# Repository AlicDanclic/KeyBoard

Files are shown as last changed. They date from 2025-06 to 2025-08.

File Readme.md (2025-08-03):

<center><h1>客制化键盘 -- 主键盘部分</h1></center>

<hr style="border: none; height: 2px; background: linear-gradient(to right, #ff0000, #ff7f00, #ffff00, #00ff00, #0000ff, #4b0082, #8f00ff); width: 100%; margin: 0 auto;">
<div style="text-align: center; font-family: 'Times New Roman', serif; margin: 20px auto; max-width: 800px;">
    <div style="margin: 20px 0;">
    	User
    </div>
    <div style="font-weight: bold; font-size: 18px; color: #333; margin: 10px 0;">
    	Copyright Statement
    </div>
    <div style="font-size: 14px; color: #666; margin: 5px 0; font-family: 'SimSun', 'Times New Roman', serif;">
    	本文档/代码/作品受版权保护，版权所有@EternoPax。保留所有权利。
    </div>
    <div style="font-size: 14px; color: #666; margin: 5px 0; font-family: 'SimSun', 'Times New Roman', serif;">
        未经允许请勿转载<br>
        Do not reproduce without permission
    </div>
    <div style="font-size: 14px; color: #666; margin: 5px 0; font-family: 'SimSun', 'Times New Roman', serif;">
        联系我👉EternoPax@outlook.con
    </div>
    <div style="display: flex; align-items: center; justify-content: center; margin: 5px 0;">
        <span style="font-size: 14px; color: #666; font-family: 'SimSun', 'Times New Roman', serif; margin-right: 10px;">
            @Copyright EternoPax
        </span>
        Copyright
    </div>
</div>
<hr style="border: none; height: 2px; background: linear-gradient(to right, #ff0000, #ff7f00, #ffff00, #00ff00, #0000ff, #4b0082, #8f00ff); width: 100%; margin: 0 auto;">

> 作为一个客制化键盘的主键盘,在这里我将介绍我的学习过程,希望一起学习

### 基础介绍

作为一个客制化键盘来说,最基础的部分有外壳,PCB,定位板,键轴和键帽,而其他多大都是辅助使用,有了这些东西就基本可以做出来一个客制化键盘了。

### 键盘布局

> [Keyboard Layout Editor](https://www.keyboard-layout-editor.com/?ref=producthunt#/)

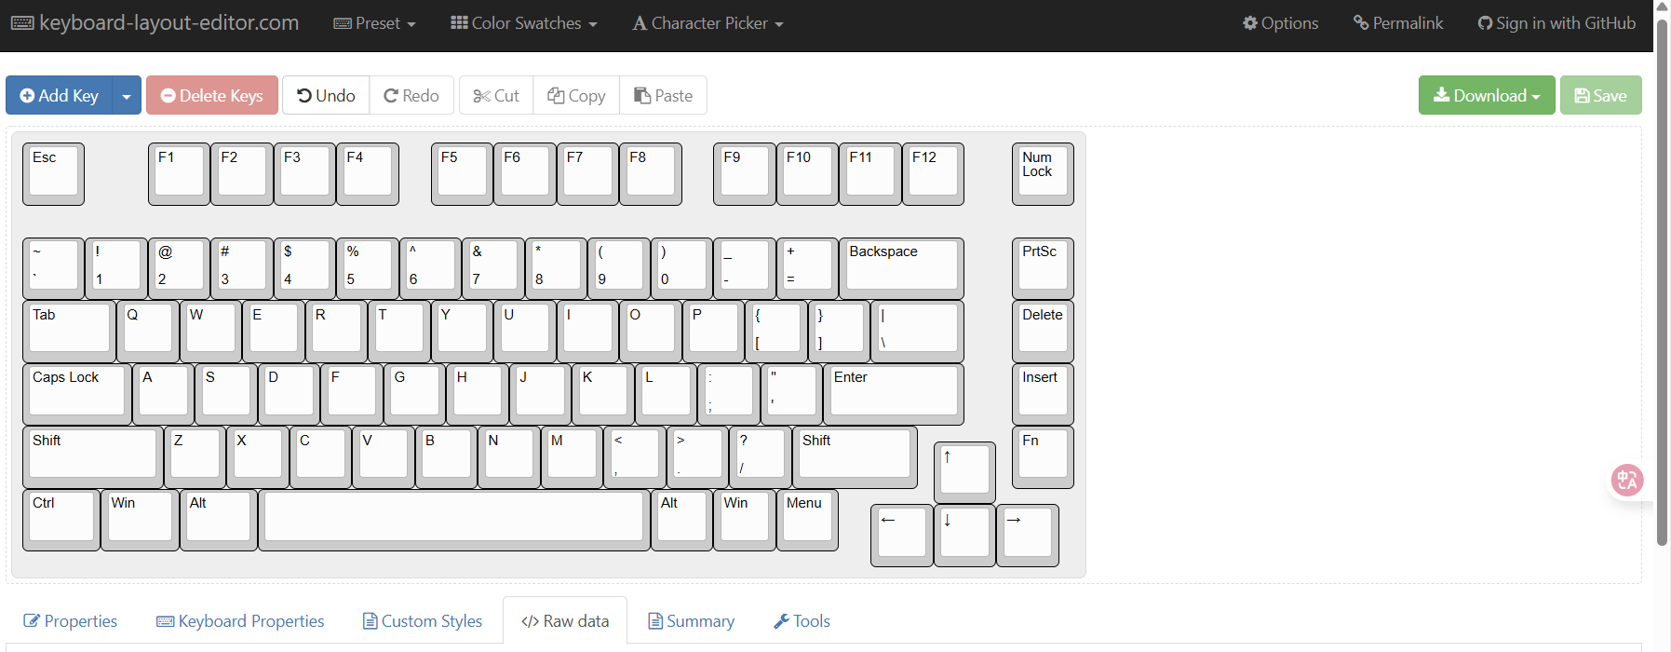
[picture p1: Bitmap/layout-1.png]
layout-1


这是通过网站设计的键盘布局,虽然这个网站的功能很多,当实际上用不到,笔者就简单介绍一下个人常用的几个功能.

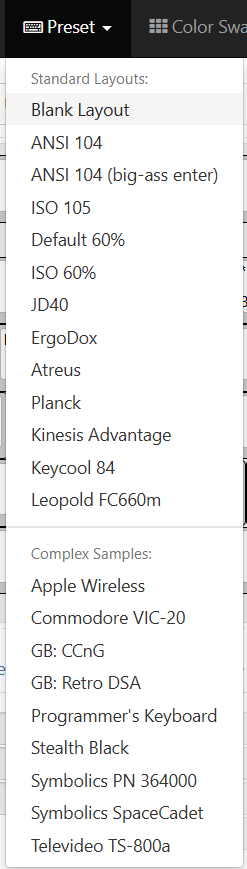
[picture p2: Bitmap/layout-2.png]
layout-2


在PreSet里面是我们常见的键盘布局,个人比较喜欢在ANSI104全键盘的基础上进行删减.

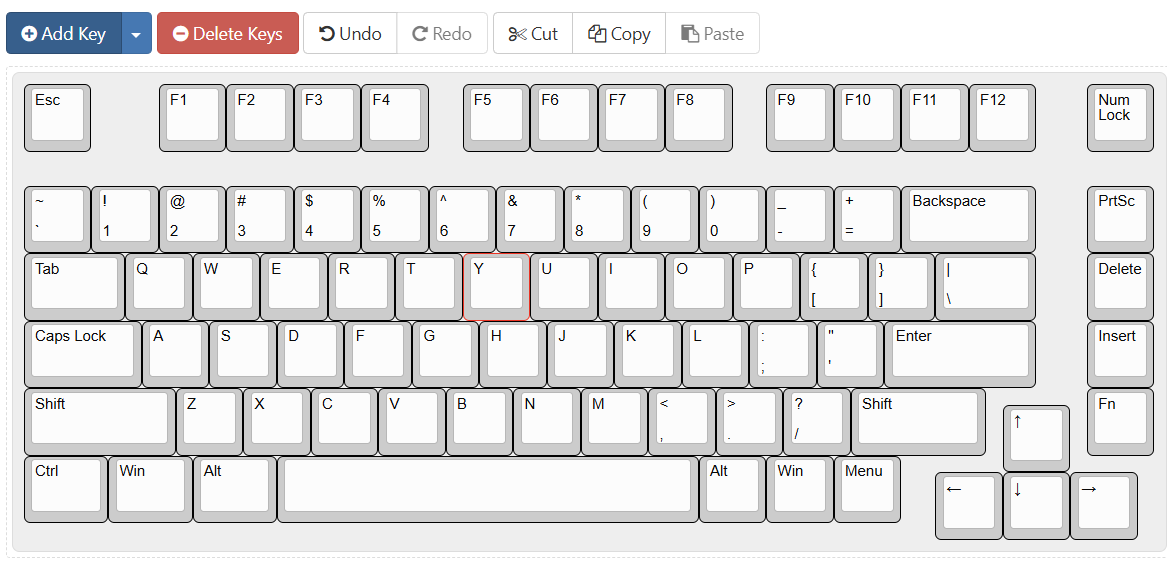
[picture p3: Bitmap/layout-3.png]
layout-3


在当你选中其中的一个按键,上边的DeleteKeys会亮起,你可以直接使用Delete进行删除,也可以左键选中按下Delete一起删除(注意:选中会出现一个框,只有完全在框里的按键会被选中)

选中按键后可以按下方向键来调整位置

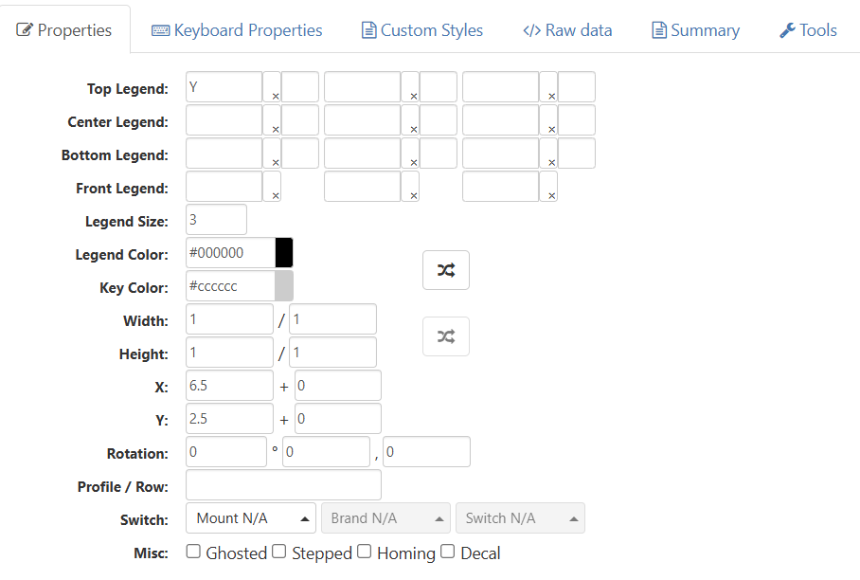
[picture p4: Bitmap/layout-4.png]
layout-4


在

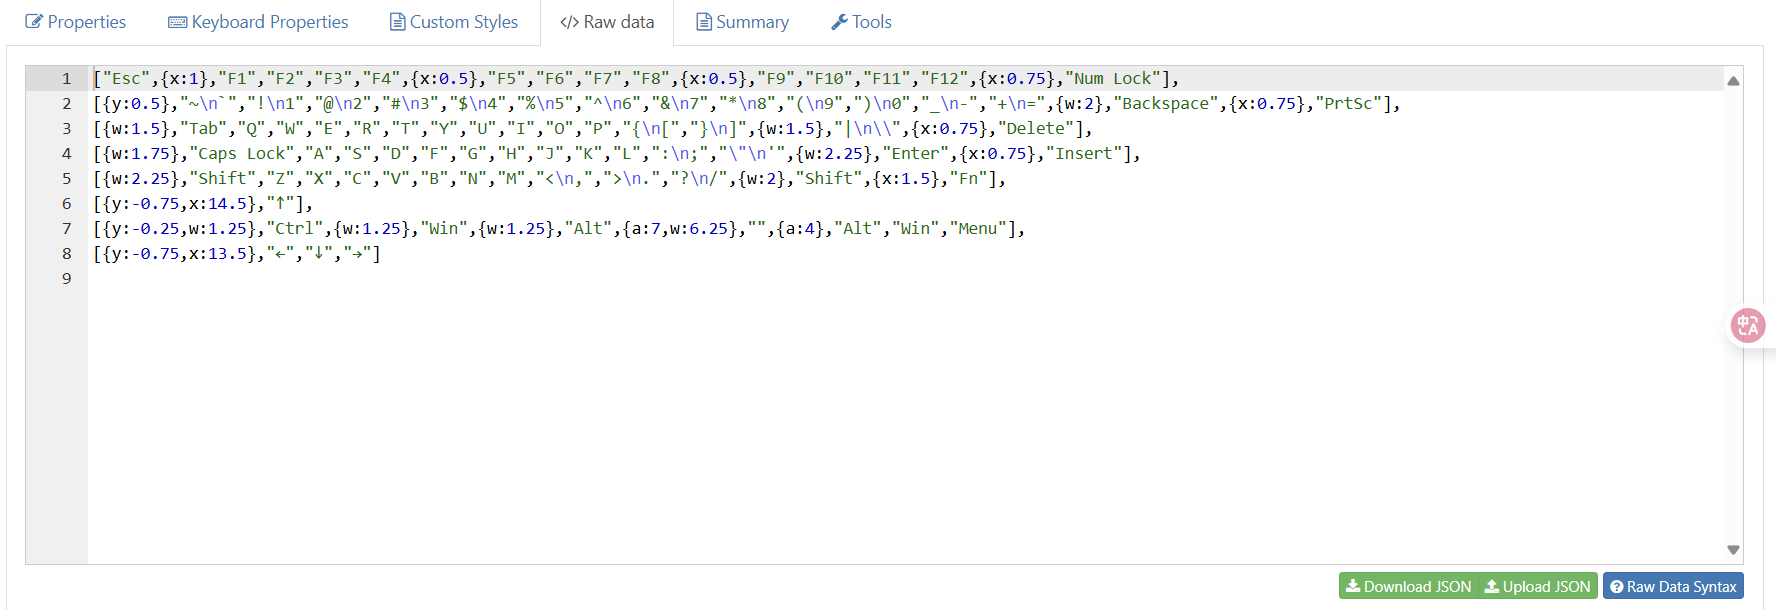
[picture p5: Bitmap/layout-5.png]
layout-5


在Raw data里面是我们键盘的布局格式,这个是我们以后用来绘制CAD的数据

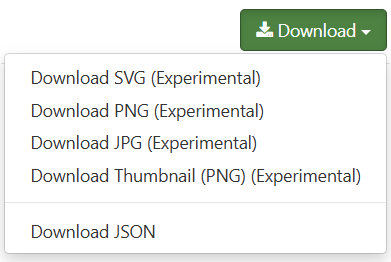
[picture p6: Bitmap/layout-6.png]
layout-6


在右上角可以看到Download,请你再绘制好之后务必下载JSON和SVG,其中JSON是为了方便以后再进行layout的修改,而SVG是为了之后的键帽设计做准备.

### 原理图绘制

### PCB绘制

### 键帽设计

### 3D外壳

### 固件编写

### 最终成果

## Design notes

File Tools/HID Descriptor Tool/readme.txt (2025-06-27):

Descriptor Tool, Version 2.4

The major changes to 2.4 are:

1) Fixed monitor enumerated values. Needed to have usage 1 display "Enum 0".
   Added REPEATING0 option to .UPG files to fix this.

2) Added a title bar to the Usage Page Dialog box.

3) Fixed incorrect Extended Usages during inital insertion.

4) Added concatonation of Ordinal Instance value to Usages in collection
   immediately following Ordinal declaration.

5) Fixed display of Extended Usages when No Data option is selected.

6) Added support for Vendor Defined Usage Tables.

The major changes to Version 2.3 are:

1) added sizable window

The major changes to 2.0 are:

1) Incorporated the HID syntax checker from HIDview.

2) The Usage Pages are all ASCII files that can be modified by the user.

3) Extended Usages are supported.

4) Added cut and paste.

5) Report Descriptors files can be saved as .HID, .TXT, .INC, and .H. Only .HID can be read. 

6) Included examples from the HID spec. and the Usage Table document.

7) Fixed numerous bugs.

/************************************************************************
Instructions:

DT.INI must reside in the same directory as DT.EXE.

Usage pages can be added or modified. To add a Usage Page create a text
.UPG file as described below then add an Usage Page (UPn) entry to DT.INI.

NOTE: When saving a file in a format other than .HID be sure to
change the extension otherwise the .HID file will be overwritten.

****************************     WARNING      ***************************
The usages pages (.UPG files) from the 9.0 Release Candidate USB HID Usage
Tables document are included here. These pages are included for convienence
and may change in the final release of the document.
****************************     WARNING      ***************************

/************************************************************************
HID Spec issues:

1) Vendor defined Collection IDs are not supported by DT.

2) Extended Usages are 32-bit usages where the high order 16-bits are the
Usage Page ID and the low order 16-bits are the Usage ID. These are useful
when usages from different Usage Pages are required for the same Main Item.
Memphis supports extended usages. Extended Usages are not defined in the
HID 1.0 Specification.

3) Extended usage values for Usage Minimum and Maximum (32 bit parameters)
are also supported by DT. Memphis supports this too.

4) Memphis has the following restrictions on delimiters:
 - Do not use delimiters for usages associated with top level (application)
       collections.
 - Only Usages are supported in delimiters. Usage Min, Usage Max, Designators
       and Strings are NOT allowed in a delimited set.
 - Delimiters are not allowed when defining usages associated with an Array.

5) The checker (Parse Descriptor) does not support:
 -- Push and Pop - False errors will be reported due to state variables that
are not saved and restored.

 -- Extended Usages - The checker will report extended usages as "undefined"
because it does not break the 32-bit value into Usage and Usage Page.

Report problems to: steve_mcgowan@ccm.jf.intel.com

/************************************************************************
File format definitions:

/************************************************************************
.INI format

[UsagePages]
Count=<total number of usage pages declared>
UP0=<Usage Page ID>,<Usage Page Name>,<.UPG File Name>
UP1=...
...
UP<Count - 1>=...

  UPn, where n increments from 0 to the number of pages declared - 1

Notes:
  The .INI file must be in the same directory as DT.EXE.

  The Usage Page ID is in decimal.

  The Usage Page Name must be identical to that found in the .UPG file.

  The .UPG File Name can include a path.

*************************************************************************
.UPG format

There are 2 types of .UPG files: NORMAL and REPEATING.

NORMAL .UPG files

<Usage Page Name>
<.UPG File Type Flag: NORMAL>
<Usage ID><tab ('\t')><Usage Name> or
; Comment if ';' is first character of a line (ignored) or
<Usage ID-Usage ID><tab><Reserved of reserved> (ignored)

	Notes:
	The Usage Page Name must be identical to the Usage Page Name referred
	to in the .INI file to be recognized as a .UPG file.

	No blank lines can be in the file.

    The Usage ID is in hexidecimal with NO "0x" notation preceeding it
	or "h" following it.

	There are three forms that can follow the File Type Flag:
		1) The Usage ID, followed by a tab character, followed by the
		Usage Name Spaces are allowed in Usage names.
		2) Any line with a semi-colon as the first character is
		considered a comment and ignored.
		3) Any line that has  "Reserved" of "reserved" as the
		Usage Name will be considered a comment and ignored.
		4) Comments are only allowed after the UPG File Type Flag.

  Example:

Generic Desktop
NORMAL
00	Undefined
01	Pointer
02	Mouse
03	Reserved
04	Joystick
05	Game Pad
06	Keyboard
07	Keypad
08-2F	Reserved
30	X
...
81	System Power
82	System Sleep
83-FFFF	Reserved

REPEATING .UPG files

<Usage Page Name>
<.UPG File Type Flag: REPEATING>
00<tab ('\t')><first Usage Name>
01<tab ('\t')><repeated Usage Name>
; Comment if ';' is first character of a line (ignored)

	Notes:
	The Usage Page Name must be identical to the Usage Page Name referred
	to in the .INI file to be recognized as a .UPG file.

	No blank lines can be in the file.

	Only 2 usages are declared. The Usage Name of the first entry (00)
	will be used for the first usage and the Usage Name of the second
	entry will be repeated followed by <space><Usage ID>.

	There are three forms that can follow the File Type Flag:
		1) The Usage ID, followed by a tab character, followed by the
		Usage Name Spaces are allowed in Usage names.
		2) Any line with a semi-colon as the first character is
		considered a comment and ignored.
		3) Any line that has  "Reserved" of "reserved" as the
		Usage Name will be considered a comment and ignored.
		4) Comments are only allowed after the UPG File Type Flag.

  Example:

Button
REPEATING
00	Unused
01	Button

  Results in the usages:

Unused
Button 1
Button 2
Button 3
...

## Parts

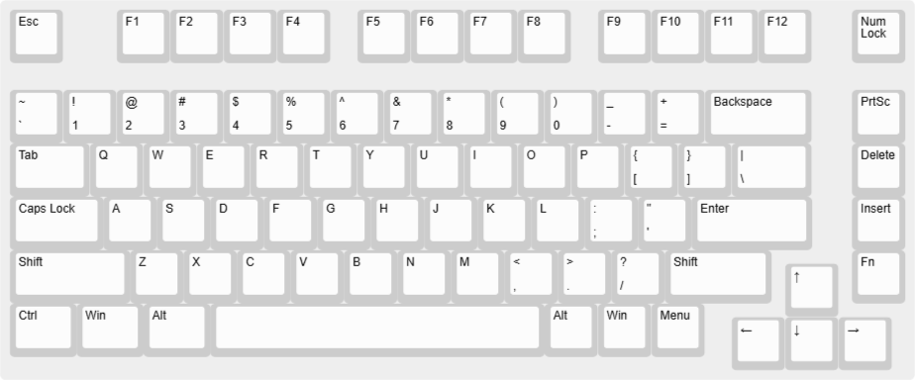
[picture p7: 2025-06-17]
Bitmap/keyboard-order.png

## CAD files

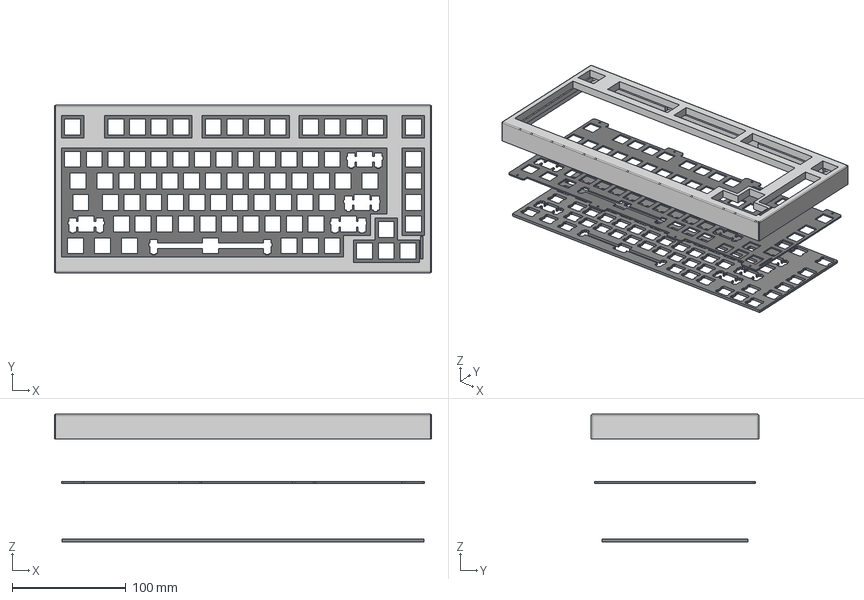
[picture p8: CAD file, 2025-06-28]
Hardware/3D/键盘.step
332.0 x 147.5 x 112.5 mm
零部件1
零部件2

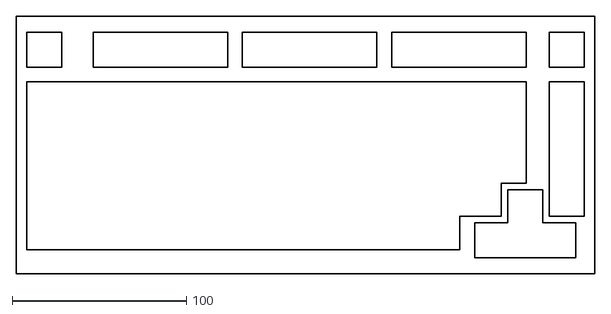
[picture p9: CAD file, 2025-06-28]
Hardware/CAD/Enclosure.dxf
332.0 x 147.5

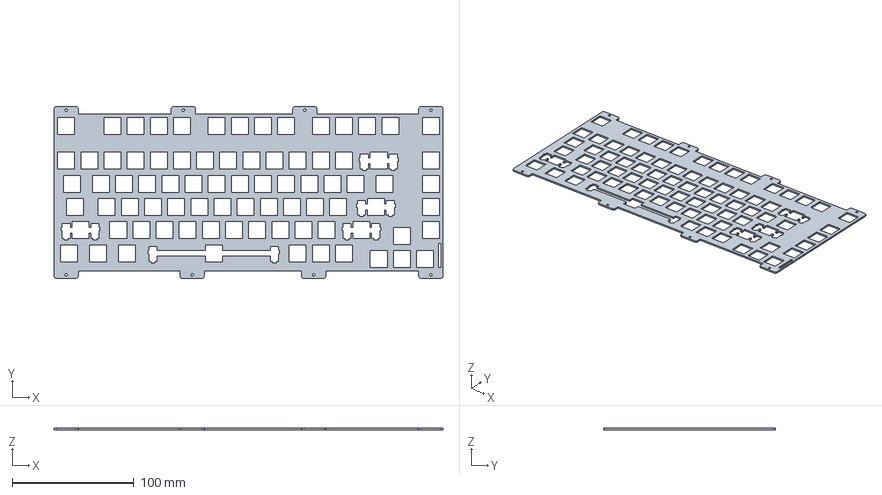
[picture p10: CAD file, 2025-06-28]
Hardware/3D/定位板.step
320.0 x 141.5 x 1.50 mm

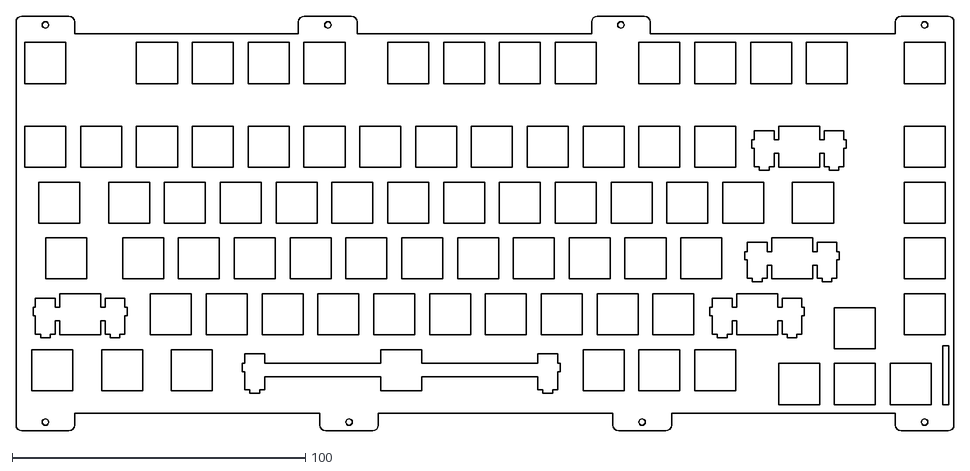
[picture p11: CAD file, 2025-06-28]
Hardware/CAD/Locating plates.dxf
320.0 x 141.5

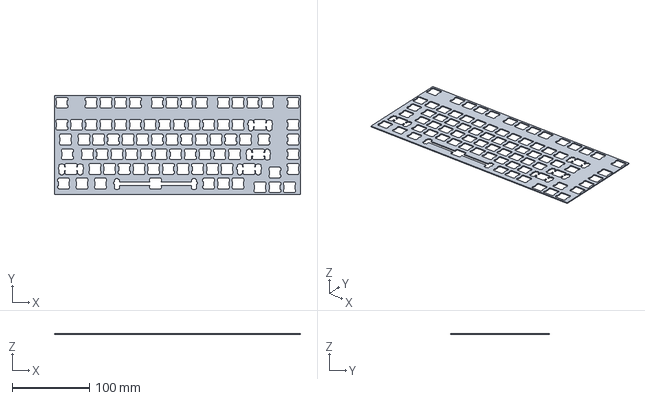
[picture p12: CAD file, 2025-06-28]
Hardware/3D/PCB模拟.step
319.1 x 128.6 x 1.20 mm

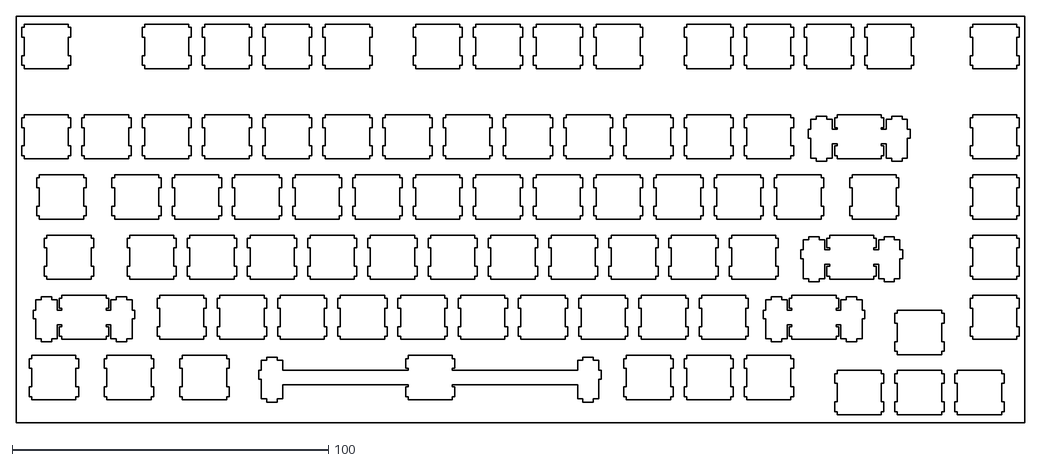
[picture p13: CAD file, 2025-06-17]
Hardware/CAD/PCB_Layout.dxf
319.1 x 128.6

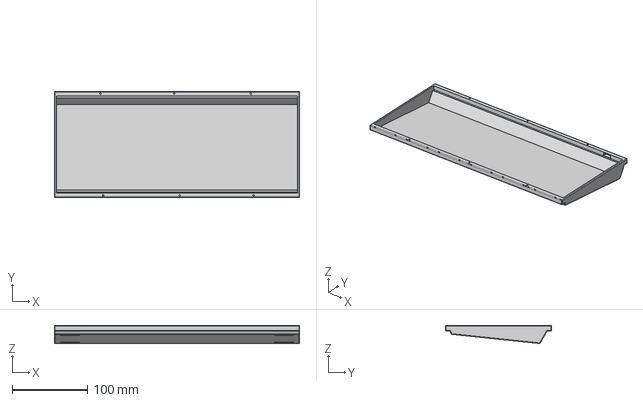
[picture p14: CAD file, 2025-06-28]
Hardware/3D/下壳.step
325.9 x 141.4 x 24.0 mm

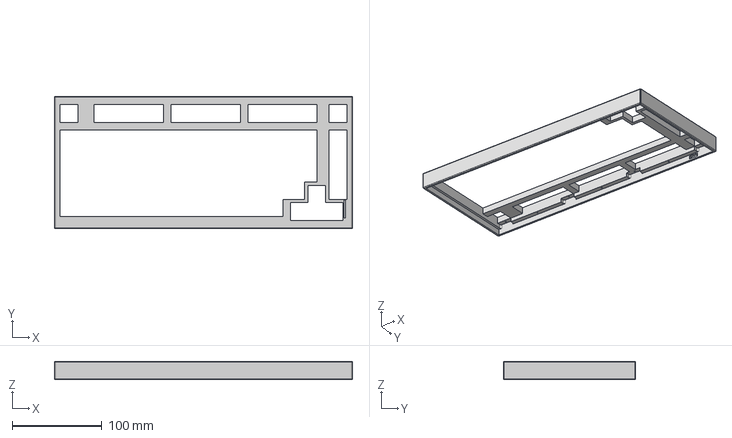
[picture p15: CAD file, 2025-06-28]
Hardware/3D/顶壳.step
332.0 x 147.5 x 20.5 mm

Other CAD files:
Hardware/3D/键盘.f3d

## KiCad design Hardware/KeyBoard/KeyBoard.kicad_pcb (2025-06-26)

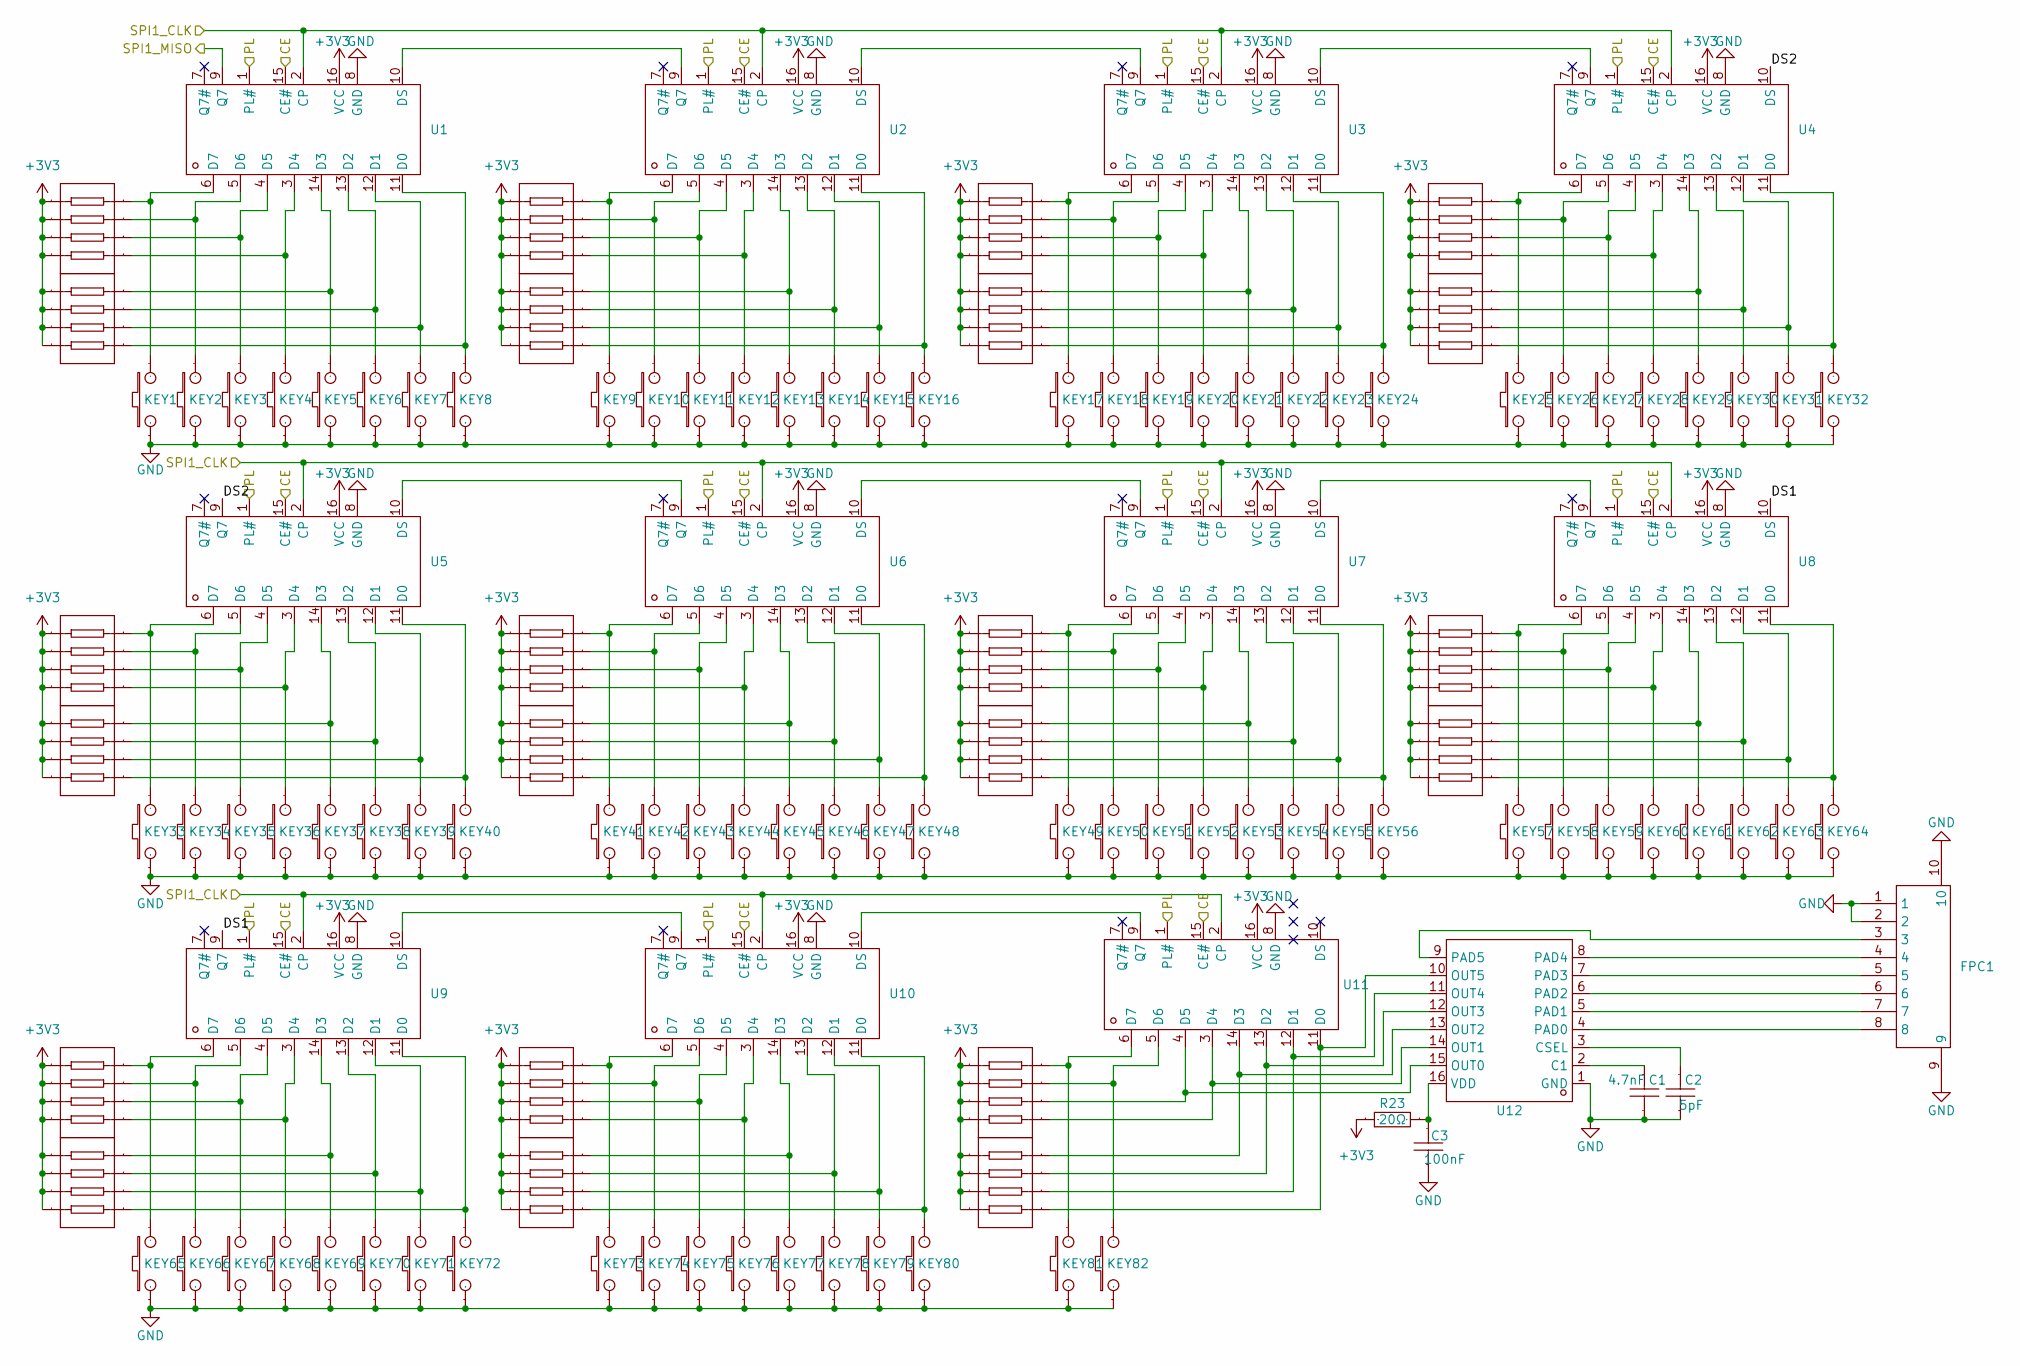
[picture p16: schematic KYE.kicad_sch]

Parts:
C1: 4.7nF; C0402; Manufacturer Part 0402B472K500NT; LCSC Part Name 4.7nF ±10% 50V
C2: 5pF; C0402; Manufacturer Part 0402B472K500NT; LCSC Part Name 4.7nF ±10% 50V
C3: 100nF; C0402; Manufacturer Part 0402B472K500NT; LCSC Part Name 4.7nF ±10% 50V
FPC1: FPC-SMD_P0.50-8P_FGS-XJ-H2.0; Manufacturer Part AFC01-S08FCA-00; LCSC Part Name 0.5mm P数:8 翻盖式 下接
KEY1, KEY2, KEY3, KEY4, KEY5, KEY6, KEY7, KEY8, KEY9, KEY10, KEY11, KEY12, KEY13, KEY14, KEY15, KEY16, KEY17, KEY18, KEY19, KEY20, KEY21, KEY22, KEY23, KEY24, KEY25, KEY26, KEY27, KEY28, KEY29, KEY30, KEY31, KEY32, KEY33, KEY34, KEY35, KEY36, KEY37, KEY38, KEY39, KEY40, KEY41, KEY42, KEY43, KEY44, KEY45, KEY46, KEY47, KEY48, KEY49, KEY50, KEY51, KEY52, KEY53, KEY54, KEY55, KEY56, KEY57, KEY58, KEY59, KEY60, KEY61, KEY62, KEY63, KEY64, KEY65, KEY66, KEY67, KEY68, KEY69, KEY70, KEY71, KEY72, KEY73, KEY74, KEY75, KEY76, KEY77, KEY78, KEY79, KEY80, KEY81, KEY82: MX-KEY-INSTALLED
R1, R2, R3, R4, R5, R6, R7, R8, R9, R10, R11, R12, R13, R14, R15, R16, R17, R18, R19, R20, R21, R22: 10kΩ; RES-ARRAY-SMD_0603-8P-L3.2-W1.6-BL; Manufacturer Part 4D03WGJ0103T5E; LCSC Part Name 10kΩ ±5%
R23: 20Ω; R0402; Manufacturer Part 0402WGF220JTCE; LCSC Part Name 22Ω ±1% 62.5mW
U1, U2, U3, U4, U5, U6, U7, U8, U9, U10, U11: SOIC-16_L9.9-W3.9-P1.27-LS6.0-BL; Manufacturer Part 74HC165D,653; LCSC Part Name 74HC165D,653
U12: SOP-16_L10.0-W3.9-P1.27-LS6.0-BL; Manufacturer Part XW06A; LCSC Part Name XW06A

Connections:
+3V3: R1.5, R1.6, R1.7, R1.8, R2.5, R2.6, R2.7, R2.8, R3.5, R3.6, R3.7, R3.8, R4.5, R4.6, R4.7, R4.8, R5.5, R5.6, R5.7, R5.8, R6.5, R6.6, R6.7, R6.8, R7.5, R7.6, R7.7, R7.8, R8.5, R8.6, R8.7, R8.8, R9.5, R9.6, R9.7, R9.8, R10.5, R10.6, R10.7, R10.8, R11.5, R11.6, R11.7, R11.8, R12.5, R12.6, R12.7, R12.8, R13.5, R13.6, R13.7, R13.8, R14.5, R14.6, R14.7, R14.8, R15.5, R15.6, R15.7, R15.8, R16.5, R16.6, R16.7, R16.8, R17.5, R17.6, R17.7, R17.8, R18.5, R18.6, R18.7, R18.8, R19.5, R19.6, R19.7, R19.8, R20.5, R20.6, R20.7, R20.8, R21.5, R21.6, R21.7, R21.8, R22.5, R22.6, R22.7, R22.8, R23.1, U1.16 (VCC), U2.16 (VCC), U3.16 (VCC), U4.16 (VCC), U5.16 (VCC), U6.16 (VCC), U7.16 (VCC), U8.16 (VCC), U9.16 (VCC), U10.16 (VCC), U11.16 (VCC); also elsewhere on the board
/KEY/CE: U1.15 (CE#), U2.15 (CE#), U3.15 (CE#), U4.15 (CE#), U5.15 (CE#), U6.15 (CE#), U7.15 (CE#), U8.15 (CE#), U9.15 (CE#), U10.15 (CE#), U11.15 (CE#); also elsewhere on the board
/KEY/DS1: U8.10 (DS), U9.9 (Q7)
/KEY/DS2: U4.10 (DS), U5.9 (Q7)
/KEY/PL: U1.1 (PL#), U2.1 (PL#), U3.1 (PL#), U4.1 (PL#), U5.1 (PL#), U6.1 (PL#), U7.1 (PL#), U8.1 (PL#), U9.1 (PL#), U10.1 (PL#), U11.1 (PL#); also elsewhere on the board
/KEY/SPI1_CLK: U1.2 (CP), U2.2 (CP), U3.2 (CP), U4.2 (CP), U5.2 (CP), U6.2 (CP), U7.2 (CP), U8.2 (CP), U9.2 (CP), U10.2 (CP), U11.2 (CP); also elsewhere on the board
/KEY/SPI1_MISO: U1.9 (Q7); also elsewhere on the board
GND: C1.2, C2.1, C3.1, FPC1.1, FPC1.2, FPC1.9, FPC1.10, KEY1.1, KEY2.1, KEY3.1, KEY4.1, KEY5.1, KEY6.1, KEY7.1, KEY8.1, KEY9.1, KEY10.1, KEY11.1, KEY12.1, KEY13.1, KEY14.1, KEY15.1, KEY16.1, KEY17.1, KEY18.1, KEY19.1, KEY20.1, KEY21.1, KEY22.1, KEY23.1, KEY24.1, KEY25.1, KEY26.1, KEY27.1, KEY28.1, KEY29.1, KEY30.1, KEY31.1, KEY32.1, KEY33.1, KEY34.1, KEY35.1, KEY36.1, KEY37.1, KEY38.1, KEY39.1, KEY40.1, KEY41.1, KEY42.1, KEY43.1, KEY44.1, KEY45.1, KEY46.1, KEY47.1, KEY48.1, KEY49.1, KEY50.1, KEY51.1, KEY52.1, KEY53.1, KEY54.1, KEY55.1, KEY56.1, KEY57.1, KEY58.1, KEY59.1, KEY60.1, KEY61.1, KEY62.1, KEY63.1, KEY64.1, KEY65.1, KEY66.1, KEY67.1, KEY68.1, KEY69.1, KEY70.1, KEY71.1, KEY72.1, KEY73.1, KEY74.1, KEY75.1, KEY76.1, KEY77.1, KEY78.1, KEY79.1, KEY80.1, KEY81.1, KEY82.1, U1.8 (GND), U2.8 (GND), U3.8 (GND), U4.8 (GND), U5.8 (GND), U6.8 (GND), U7.8 (GND), U8.8 (GND), U9.8 (GND), U10.8 (GND), U11.8 (GND), U12.1 (GND); also elsewhere on the board
unnamed: KEY8.2, R2.4, U1.11 (D0)
unnamed: KEY7.2, R2.3, U1.12 (D1)
unnamed: KEY6.2, R2.2, U1.13 (D2)
unnamed: KEY5.2, R2.1, U1.14 (D3)
unnamed: KEY4.2, R1.4, U1.3 (D4)
unnamed: KEY3.2, R1.3, U1.4 (D5)
unnamed: KEY2.2, R1.2, U1.5 (D6)
unnamed: KEY1.2, R1.1, U1.6 (D7)
unnamed: U1.10 (DS), U2.9 (Q7)
unnamed: KEY16.2, R4.4, U2.11 (D0)
unnamed: KEY15.2, R4.3, U2.12 (D1)
unnamed: KEY14.2, R4.2, U2.13 (D2)
unnamed: KEY13.2, R4.1, U2.14 (D3)
unnamed: KEY12.2, R3.4, U2.3 (D4)
unnamed: KEY11.2, R3.3, U2.4 (D5)
unnamed: KEY10.2, R3.2, U2.5 (D6)
unnamed: KEY9.2, R3.1, U2.6 (D7)
unnamed: U2.10 (DS), U3.9 (Q7)
unnamed: KEY24.2, R6.4, U3.11 (D0)
unnamed: KEY23.2, R6.3, U3.12 (D1)
unnamed: KEY22.2, R6.2, U3.13 (D2)
unnamed: KEY21.2, R6.1, U3.14 (D3)
unnamed: KEY20.2, R5.4, U3.3 (D4)
unnamed: KEY19.2, R5.3, U3.4 (D5)
unnamed: KEY18.2, R5.2, U3.5 (D6)
unnamed: KEY17.2, R5.1, U3.6 (D7)
unnamed: U3.10 (DS), U4.9 (Q7)
unnamed: KEY32.2, R8.4, U4.11 (D0)
unnamed: KEY31.2, R8.3, U4.12 (D1)
unnamed: KEY30.2, R8.2, U4.13 (D2)
unnamed: KEY29.2, R8.1, U4.14 (D3)
unnamed: KEY28.2, R7.4, U4.3 (D4)
unnamed: KEY27.2, R7.3, U4.4 (D5)
unnamed: KEY26.2, R7.2, U4.5 (D6)
unnamed: KEY25.2, R7.1, U4.6 (D7)
unnamed: KEY40.2, R10.4, U5.11 (D0)
unnamed: KEY39.2, R10.3, U5.12 (D1)
unnamed: KEY38.2, R10.2, U5.13 (D2)
unnamed: KEY37.2, R10.1, U5.14 (D3)
unnamed: KEY36.2, R9.4, U5.3 (D4)
unnamed: KEY35.2, R9.3, U5.4 (D5)
unnamed: KEY34.2, R9.2, U5.5 (D6)
unnamed: KEY33.2, R9.1, U5.6 (D7)
unnamed: U5.10 (DS), U6.9 (Q7)
unnamed: KEY48.2, R12.4, U6.11 (D0)
unnamed: KEY47.2, R12.3, U6.12 (D1)
unnamed: KEY46.2, R12.2, U6.13 (D2)
unnamed: KEY45.2, R12.1, U6.14 (D3)
unnamed: KEY44.2, R11.4, U6.3 (D4)
unnamed: KEY43.2, R11.3, U6.4 (D5)
unnamed: KEY42.2, R11.2, U6.5 (D6)
unnamed: KEY41.2, R11.1, U6.6 (D7)
unnamed: U6.10 (DS), U7.9 (Q7)
unnamed: KEY56.2, R14.4, U7.11 (D0)
unnamed: KEY55.2, R14.3, U7.12 (D1)
unnamed: KEY54.2, R14.2, U7.13 (D2)
unnamed: KEY53.2, R14.1, U7.14 (D3)
unnamed: KEY52.2, R13.4, U7.3 (D4)
unnamed: KEY51.2, R13.3, U7.4 (D5)
unnamed: KEY50.2, R13.2, U7.5 (D6)
unnamed: KEY49.2, R13.1, U7.6 (D7)
unnamed: U7.10 (DS), U8.9 (Q7)
unnamed: KEY64.2, R16.4, U8.11 (D0)
unnamed: KEY63.2, R16.3, U8.12 (D1)
unnamed: KEY62.2, R16.2, U8.13 (D2)
unnamed: KEY61.2, R16.1, U8.14 (D3)
unnamed: KEY60.2, R15.4, U8.3 (D4)
unnamed: KEY59.2, R15.3, U8.4 (D5)
unnamed: KEY58.2, R15.2, U8.5 (D6)
unnamed: KEY57.2, R15.1, U8.6 (D7)
unnamed: KEY72.2, R18.4, U9.11 (D0)
unnamed: KEY71.2, R18.3, U9.12 (D1)
unnamed: KEY70.2, R18.2, U9.13 (D2)
unnamed: KEY69.2, R18.1, U9.14 (D3)
unnamed: KEY68.2, R17.4, U9.3 (D4)
unnamed: KEY67.2, R17.3, U9.4 (D5)
unnamed: KEY66.2, R17.2, U9.5 (D6)
unnamed: KEY65.2, R17.1, U9.6 (D7)
unnamed: KEY80.2, R20.4, U10.11 (D0)
unnamed: KEY79.2, R20.3, U10.12 (D1)
unnamed: KEY78.2, R20.2, U10.13 (D2)
unnamed: KEY77.2, R20.1, U10.14 (D3)
unnamed: KEY76.2, R19.4, U10.3 (D4)
unnamed: KEY75.2, R19.3, U10.4 (D5)
unnamed: KEY74.2, R19.2, U10.5 (D6)
unnamed: KEY73.2, R19.1, U10.6 (D7)
unnamed: U10.10 (DS), U11.9 (Q7)
unnamed: U9.10 (DS), U10.9 (Q7)
unnamed: R22.4, U11.11 (D0), U12.10 (OUT5)
unnamed: R22.3, U11.12 (D1), U12.11 (OUT4)
unnamed: R22.2, U11.13 (D2), U12.12 (OUT3)
unnamed: R22.1, U11.14 (D3), U12.13 (OUT2)
unnamed: R21.4, U11.3 (D4), U12.14 (OUT1)
unnamed: R21.3, U11.4 (D5), U12.15 (OUT0)
unnamed: KEY82.2, R21.2, U11.5 (D6)
unnamed: KEY81.2, R21.1, U11.6 (D7)
unnamed: C1.1, U12.2 (C1)
unnamed: C2.2, U12.3 (CSEL)
unnamed: FPC1.8, U12.4 (PAD0)
unnamed: FPC1.7, U12.5 (PAD1)
unnamed: FPC1.6, U12.6 (PAD2)
unnamed: FPC1.5, U12.7 (PAD3)
unnamed: FPC1.4, U12.8 (PAD4)
unnamed: FPC1.3, U12.9 (PAD5)
unnamed: C3.2, R23.2, U12.16 (VDD)

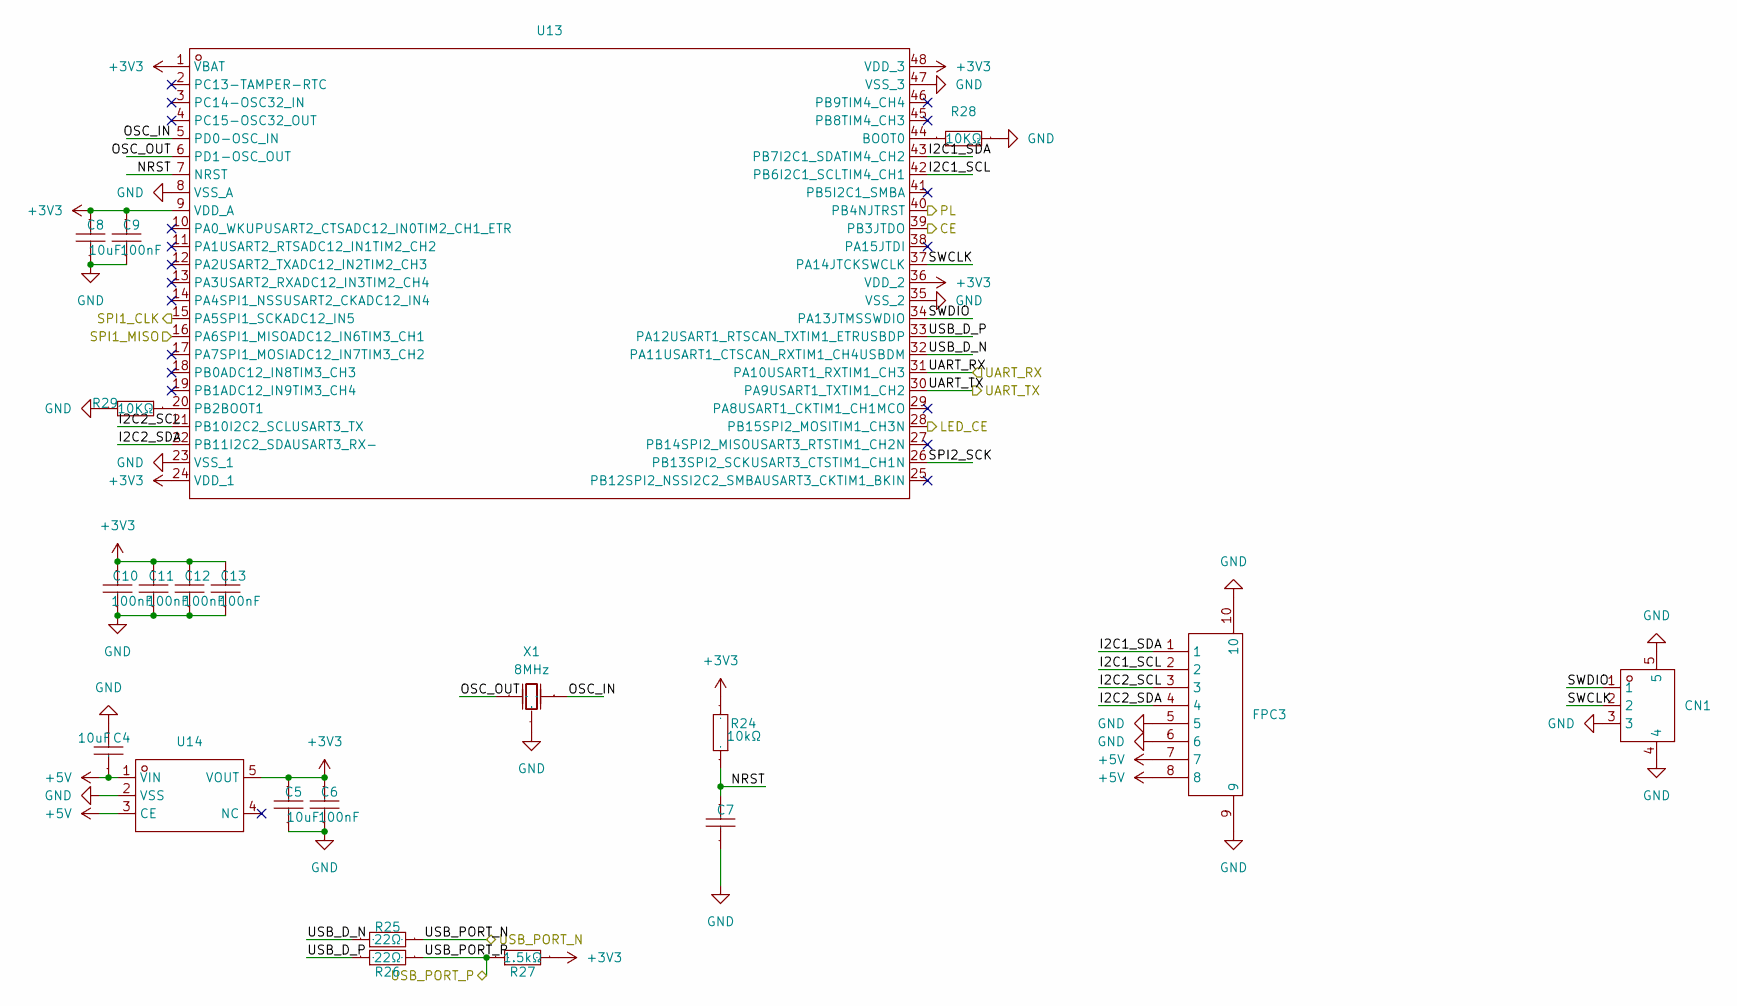
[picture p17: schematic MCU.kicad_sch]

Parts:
C4, C5, C8: 10uF; C0402; Manufacturer Part 0402B472K500NT; LCSC Part Name 4.7nF ±10% 50V
C6, C7, C9, C10, C11, C12, C13: 100nF; C0402; Manufacturer Part 0402B472K500NT; LCSC Part Name 4.7nF ±10% 50V
CN1: CONN-TH_3P-P1.25_GH1.25; Manufacturer Part WAFER-GH1.25-3PWB; LCSC Part Name 1x3P 间距:1.25mm 卧贴 系列:GH
FPC3: FPC-SMD_P0.50-8P_FGS-XJ-H2.0; Manufacturer Part AFC01-S08FCA-00; LCSC Part Name 0.5mm P数:8 翻盖式 下接
R24: 10kΩ; R0402; Manufacturer Part 0402WGF220JTCE; LCSC Part Name 22Ω ±1% 62.5mW
R25, R26: 22Ω; R0402; Manufacturer Part 0402WGF220JTCE; LCSC Part Name 22Ω ±1% 62.5mW
R27: 1.5kΩ; R0402; Manufacturer Part 0402WGF220JTCE; LCSC Part Name 22Ω ±1% 62.5mW
R28, R29: 10KΩ; R0402; Manufacturer Part 0402WGF220JTCE; LCSC Part Name 22Ω ±1% 62.5mW
U13: LQFP-48_L7.0-W7.0-P0.50-LS9.0-BL; Manufacturer Part STM32F103CBT6; LCSC Part Name STM32F103CBT6
U14: SOT-25_L3.0-W1.6-P0.95-LS2.8-BL; Manufacturer Part XC6210B332MR; LCSC Part Name Vin=6V Vout=3.3V 900mA 60dB@(1kHz)
X1: 8MHz; OSC-SMD_3P-L3.2-W1.3-P1.20; Manufacturer Part CSTNE8M00GH5C000R0; LCSC Part Name 8MHz ±0.07% 33pF

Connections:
+3V3: C5.1, C6.1, C8.1, C9.1, C10.1, C11.1, C12.1, C13.1, R24.2, R27.2, U13.1 (VBAT), U13.9 (VDD_A), U13.24 (VDD_1), U13.36 (VDD_2), U13.48 (VDD_3), U14.5 (VOUT); also elsewhere on the board
+5V: C4.1, FPC3.7, FPC3.8, U14.1 (VIN), U14.3 (CE); also elsewhere on the board
/Device/USB_1_DN: R25.2; also elsewhere on the board
/Device/USB_1_DP: R26.2, R27.1; also elsewhere on the board
/KEY/CE: U13.39 (PB3JTDO); also elsewhere on the board
/KEY/PL: U13.40 (PB4NJTRST); also elsewhere on the board
/KEY/SPI1_CLK: U13.15 (PA5SPI1_SCKADC12_IN5); also elsewhere on the board
/KEY/SPI1_MISO: U13.16 (PA6SPI1_MISOADC12_IN6TIM3_CH1); also elsewhere on the board
/LED/LED_CE: U13.28 (PB15SPI2_MOSITIM1_CH3N); also elsewhere on the board
/MCU/I2C1_SCL: FPC3.2, U13.42 (PB6I2C1_SCLTIM4_CH1)
/MCU/I2C1_SDA: FPC3.1, U13.43 (PB7I2C1_SDATIM4_CH2)
/MCU/I2C2_SCL: FPC3.3, U13.21 (PB10I2C2_SCLUSART3_TX)
/MCU/I2C2_SDA: FPC3.4, U13.22 (PB11I2C2_SDAUSART3_RX-)
/MCU/NRST: C7.1, R24.1, U13.7 (NRST)
/MCU/OSC_IN: U13.5 (PD0-OSC_IN), X1.1 (OSC1)
/MCU/OSC_OUT: U13.6 (PD1-OSC_OUT), X1.3 (OSC2)
/MCU/SPI2_SCK: U13.26 (PB13SPI2_SCKUSART3_CTSTIM1_CH1N)
/MCU/SWCLK: CN1.2, U13.37 (PA14JTCKSWCLK)
/MCU/SWDIO: CN1.1, U13.34 (PA13JTMSSWDIO)
/MCU/UART_RX: U13.31 (PA10USART1_RXTIM1_CH3); also elsewhere on the board
/MCU/UART_TX: U13.30 (PA9USART1_TXTIM1_CH2); also elsewhere on the board
/MCU/USB_D_N: R25.1, U13.32 (PA11USART1_CTSCAN_RXTIM1_CH4USBDM)
/MCU/USB_D_P: R26.1, U13.33 (PA12USART1_RTSCAN_TXTIM1_ETRUSBDP)
GND: C4.2, C5.2, C6.2, C7.2, C8.2, C9.2, C10.2, C11.2, C12.2, C13.2, CN1.3, CN1.4, CN1.5, FPC3.5, FPC3.6, FPC3.9, FPC3.10, R28.2, R29.2, U13.8 (VSS_A), U13.23 (VSS_1), U13.35 (VSS_2), U13.47 (VSS_3), U14.2 (VSS), X1.2 (GND); also elsewhere on the board
unnamed: R28.1, U13.44 (BOOT0)
unnamed: R29.1, U13.20 (PB2BOOT1)

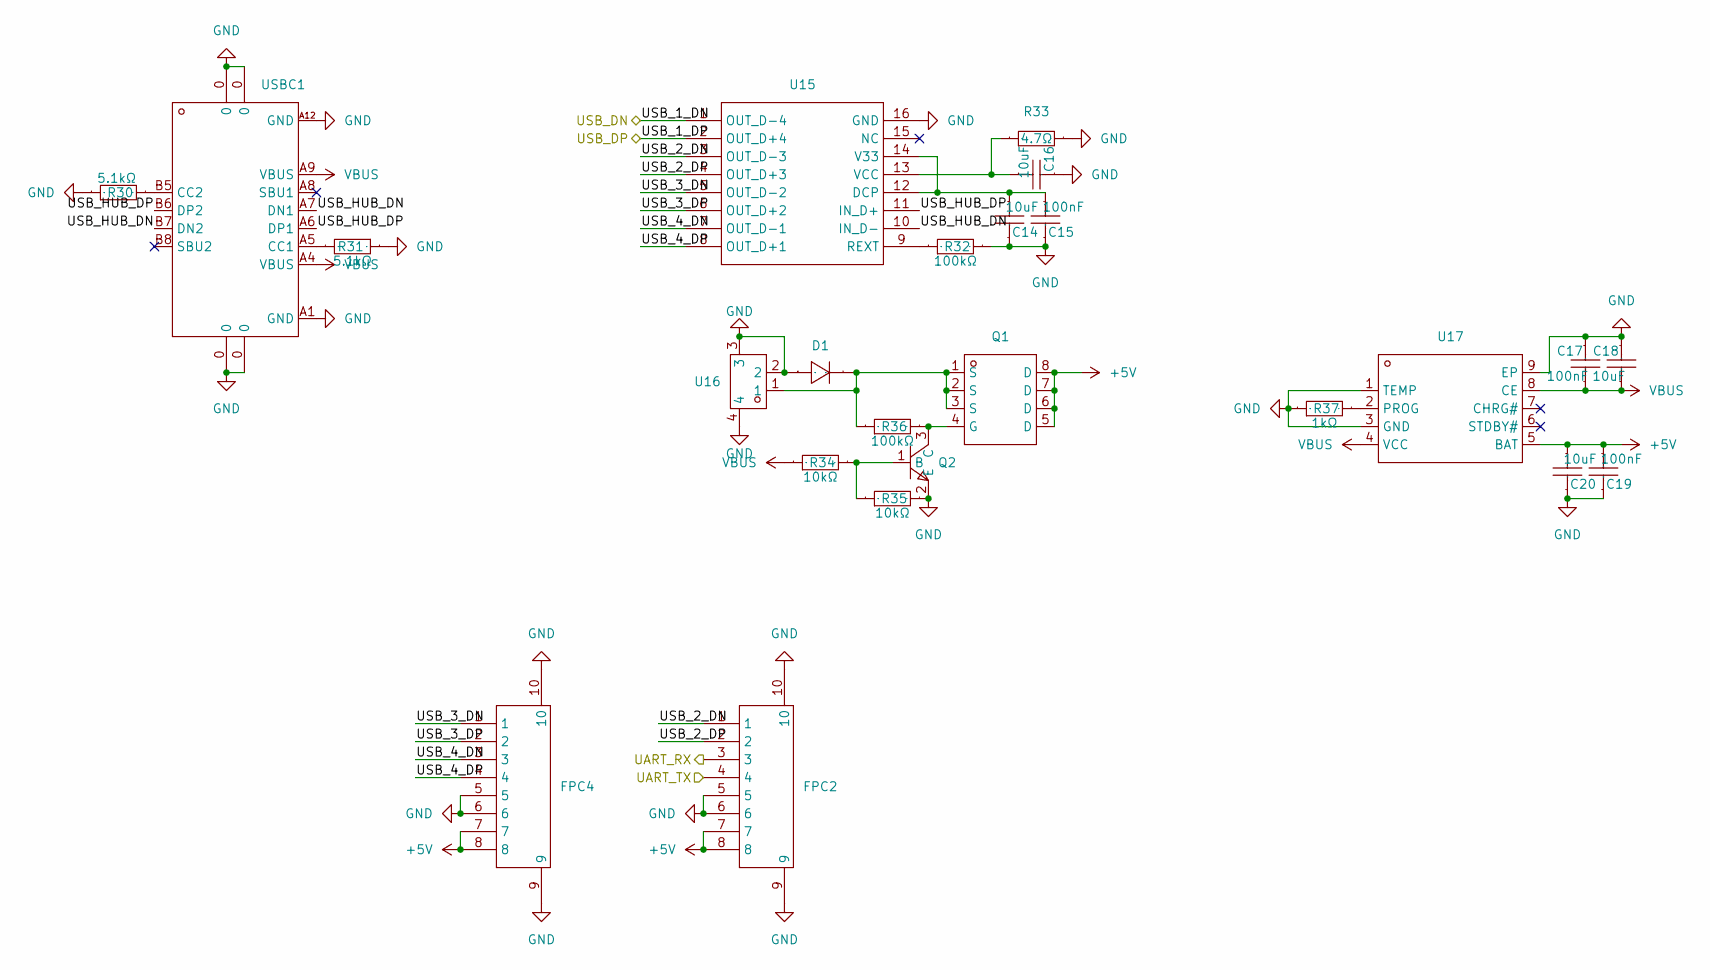
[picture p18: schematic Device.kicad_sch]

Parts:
C14, C16, C18, C20: 10uF; C0402; Manufacturer Part 0402B472K500NT; LCSC Part Name 4.7nF ±10% 50V
C15, C17, C19: 100nF; C0402; Manufacturer Part 0402B472K500NT; LCSC Part Name 4.7nF ±10% 50V
D1: SOD-523_L1.2-W0.8-LS1.6-FD; Manufacturer Part B5819WS; LCSC Part Name 40V 1A 900mV@3A
FPC2, FPC4: FPC-SMD_P0.50-8P_FGS-XJ-H2.0; Manufacturer Part AFC01-S08FCA-00; LCSC Part Name 0.5mm P数:8 翻盖式 下接
Q1: POWERTDFN-8_L3.1-W3.1-P0.65-LS3.3-BL; Manufacturer Part EMB12P03V; LCSC Part Name P沟道 30V 21A
Q2: SOT-23-3_L2.9-W1.3-P1.90-LS2.4-BR; Manufacturer Part S8050 J3Y; LCSC Part Name S8050
R30, R31: 5.1kΩ; R0402; Manufacturer Part 0402WGF220JTCE; LCSC Part Name 22Ω ±1% 62.5mW
R32, R36: 100kΩ; R0402; Manufacturer Part 0402WGF220JTCE; LCSC Part Name 22Ω ±1% 62.5mW
R33: 4.7Ω; R0402; Manufacturer Part 0402WGF220JTCE; LCSC Part Name 22Ω ±1% 62.5mW
R34, R35: 10kΩ; R0402; Manufacturer Part 0402WGF220JTCE; LCSC Part Name 22Ω ±1% 62.5mW
R37: 1kΩ; R0402; Manufacturer Part 0402WGF220JTCE; LCSC Part Name 22Ω ±1% 62.5mW
U15: SOP-16
U16: CONN-SMD_2P-P2.50_HCTL_HC-XH-2ALT; Manufacturer Part ZX-XH2.54-2PLT; LCSC Part Name XH 2.54mm 1x2P 立贴
U17: ESOP-8_L4.9-W3.9-P1.27-LS6.0-BL-EP; Manufacturer Part TP4056; LCSC Part Name 1A鋰電池充電IC
USBC1: USB-C-SMD_TYPE-C-USB-17; Manufacturer Part 918-418K2023S40001; LCSC Part Name Type-C 母座

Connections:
+5V: C19.2, C20.1, FPC2.7, FPC2.8, FPC4.7, FPC4.8, Q1.5 (D), Q1.6 (D), Q1.7 (D), Q1.8 (D), U17.5 (BAT); also elsewhere on the board
/Device/USB_1_DN: U15.1 (OUT_D-4); also elsewhere on the board
/Device/USB_1_DP: U15.2 (OUT_D+4); also elsewhere on the board
/Device/USB_2_DN: FPC2.1, U15.3 (OUT_D-3)
/Device/USB_2_DP: FPC2.2, U15.4 (OUT_D+3)
/Device/USB_3_DN: FPC4.1, U15.5 (OUT_D-2)
/Device/USB_3_DP: FPC4.2, U15.6 (OUT_D+2)
/Device/USB_4_DN: FPC4.3, U15.7 (OUT_D-1)
/Device/USB_4_DP: FPC4.4, U15.8 (OUT_D+1)
/Device/USB_HUB_DN: U15.10 (IN_D-), USBC1.A7 (DN1), USBC1.B7 (DN2)
/Device/USB_HUB_DP: U15.11 (IN_D+), USBC1.A6 (DP1), USBC1.B6 (DP2)
/MCU/UART_RX: FPC2.3; also elsewhere on the board
/MCU/UART_TX: FPC2.4; also elsewhere on the board
GND: C14.2, C15.1, C16.2, C17.1, C18.2, C19.1, C20.2, D1.1 (A), FPC2.5, FPC2.6, FPC2.9, FPC2.10, FPC4.5, FPC4.6, FPC4.9, FPC4.10, Q2.2 (E), R30.1, R31.1, R32.2, R33.2, R35.2, R37.1, U15.16 (GND), U16.2, U16.3, U16.4, U17.1 (TEMP), U17.3 (GND), U17.9 (EP), USBC1.0, USBC1.A1 (GND), USBC1.A12 (GND); also elsewhere on the board
unnamed: D1.2 (K), Q1.1 (S), Q1.2 (S), Q1.3 (S), R36.1, U16.1
unnamed: Q1.4 (G), Q2.3 (C), R36.2
unnamed: Q2.1 (B), R34.2, R35.1
unnamed: C14.1, C15.2, U15.12 (DCP), U15.14 (V33)
unnamed: R32.1, U15.9 (REXT)
unnamed: C16.1, R33.1, U15.13 (VCC)
unnamed: R37.2, U17.2 (PROG)
unnamed: R31.2, USBC1.A5 (CC1)
unnamed: R30.2, USBC1.B5 (CC2)
VBUS: C17.2, C18.1, R34.1, U17.4 (VCC), U17.8 (CE), USBC1.A4 (VBUS), USBC1.A9 (VBUS)

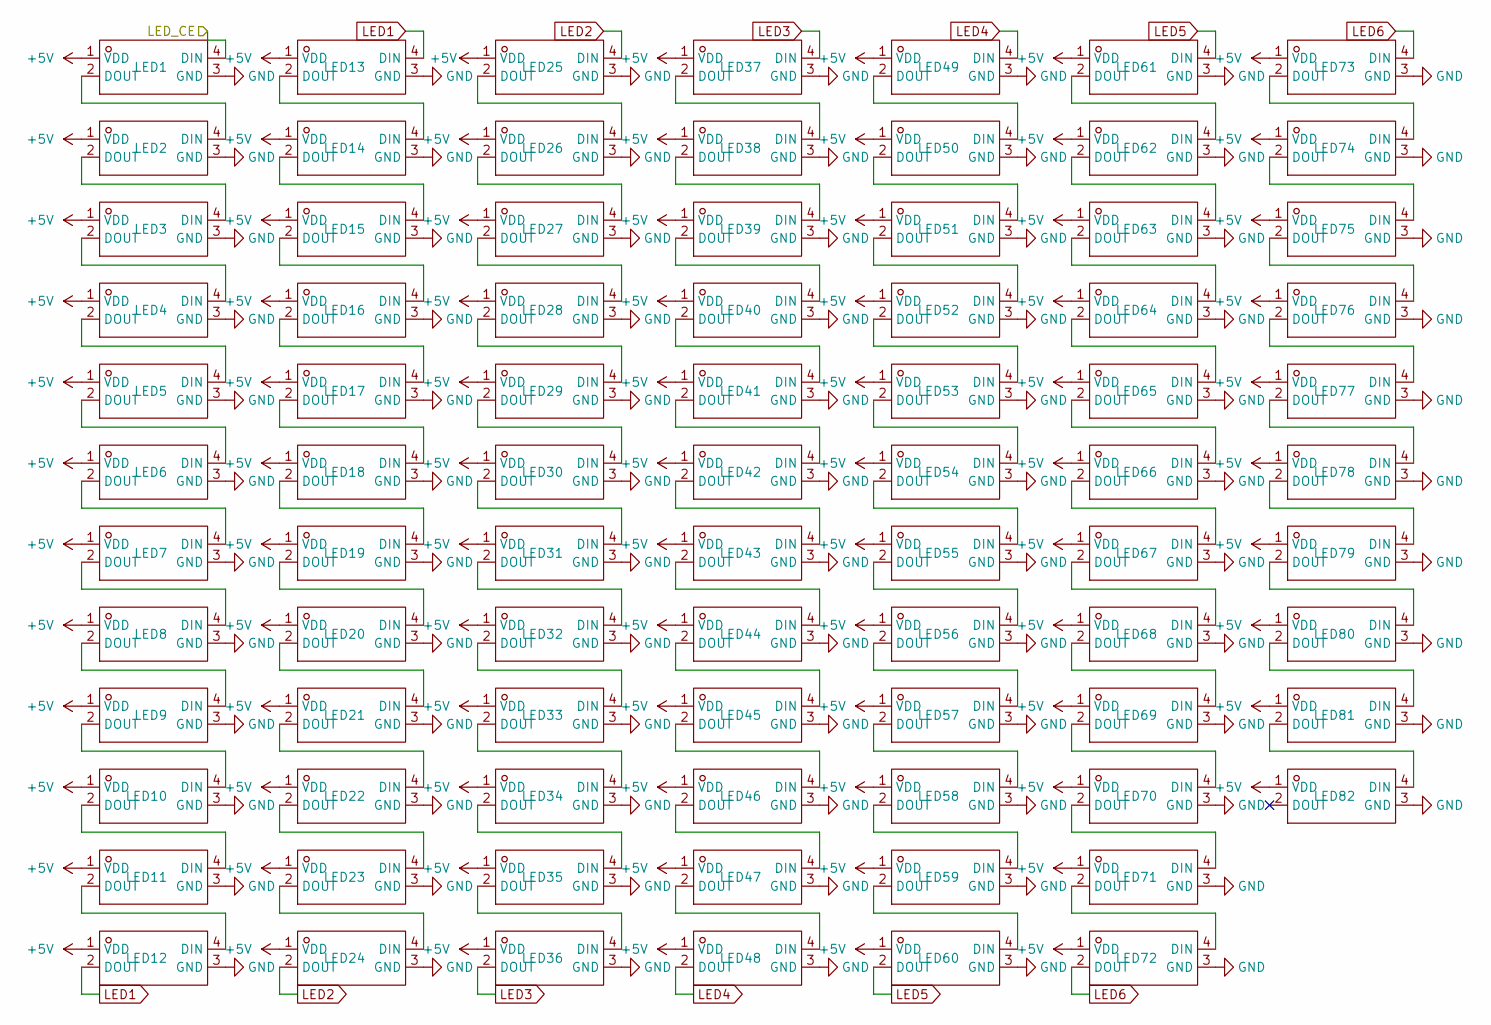
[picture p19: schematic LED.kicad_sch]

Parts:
LED1, LED2, LED3, LED4, LED5, LED6, LED7, LED8, LED9, LED10, LED11, LED12, LED13, LED14, LED15, LED16, LED17, LED18, LED19, LED20, LED21, LED22, LED23, LED24, LED25, LED26, LED27, LED28, LED29, LED30, LED31, LED32, LED33, LED34, LED35, LED36, LED37, LED38, LED39, LED40, LED41, LED42, LED43, LED44, LED45, LED46, LED47, LED48, LED49, LED50, LED51, LED52, LED53, LED54, LED55, LED56, LED57, LED58, LED59, LED60, LED61, LED62, LED63, LED64, LED65, LED66, LED67, LED68, LED69, LED70, LED71, LED72, LED73, LED74, LED75, LED76, LED77, LED78, LED79, LED80, LED81, LED82: LED-SMD_L3.2-W2.8_YO-WS2812B-3528; Manufacturer Part Yo-WS2812B-3528反贴雾状

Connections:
+5V: LED1.1 (VDD), LED2.1 (VDD), LED3.1 (VDD), LED4.1 (VDD), LED5.1 (VDD), LED6.1 (VDD), LED7.1 (VDD), LED8.1 (VDD), LED9.1 (VDD), LED10.1 (VDD), LED11.1 (VDD), LED12.1 (VDD), LED13.1 (VDD), LED14.1 (VDD), LED15.1 (VDD), LED16.1 (VDD), LED17.1 (VDD), LED18.1 (VDD), LED19.1 (VDD), LED20.1 (VDD), LED21.1 (VDD), LED22.1 (VDD), LED23.1 (VDD), LED24.1 (VDD), LED25.1 (VDD), LED26.1 (VDD), LED27.1 (VDD), LED28.1 (VDD), LED29.1 (VDD), LED30.1 (VDD), LED31.1 (VDD), LED32.1 (VDD), LED33.1 (VDD), LED34.1 (VDD), LED35.1 (VDD), LED36.1 (VDD), LED37.1 (VDD), LED38.1 (VDD), LED39.1 (VDD), LED40.1 (VDD), LED41.1 (VDD), LED42.1 (VDD), LED43.1 (VDD), LED44.1 (VDD), LED45.1 (VDD), LED46.1 (VDD), LED47.1 (VDD), LED48.1 (VDD), LED49.1 (VDD), LED50.1 (VDD), LED51.1 (VDD), LED52.1 (VDD), LED53.1 (VDD), LED54.1 (VDD), LED55.1 (VDD), LED56.1 (VDD), LED57.1 (VDD), LED58.1 (VDD), LED59.1 (VDD), LED60.1 (VDD), LED61.1 (VDD), LED62.1 (VDD), LED63.1 (VDD), LED64.1 (VDD), LED65.1 (VDD), LED66.1 (VDD), LED67.1 (VDD), LED68.1 (VDD), LED69.1 (VDD), LED70.1 (VDD), LED71.1 (VDD), LED72.1 (VDD), LED73.1 (VDD), LED74.1 (VDD), LED75.1 (VDD), LED76.1 (VDD), LED77.1 (VDD), LED78.1 (VDD), LED79.1 (VDD), LED80.1 (VDD), LED81.1 (VDD), LED82.1 (VDD); also elsewhere on the board
/LED/LED_CE: LED1.4 (DIN); also elsewhere on the board
GND: LED1.3 (GND), LED2.3 (GND), LED3.3 (GND), LED4.3 (GND), LED5.3 (GND), LED6.3 (GND), LED7.3 (GND), LED8.3 (GND), LED9.3 (GND), LED10.3 (GND), LED11.3 (GND), LED12.3 (GND), LED13.3 (GND), LED14.3 (GND), LED15.3 (GND), LED16.3 (GND), LED17.3 (GND), LED18.3 (GND), LED19.3 (GND), LED20.3 (GND), LED21.3 (GND), LED22.3 (GND), LED23.3 (GND), LED24.3 (GND), LED25.3 (GND), LED26.3 (GND), LED27.3 (GND), LED28.3 (GND), LED29.3 (GND), LED30.3 (GND), LED31.3 (GND), LED32.3 (GND), LED33.3 (GND), LED34.3 (GND), LED35.3 (GND), LED36.3 (GND), LED37.3 (GND), LED38.3 (GND), LED39.3 (GND), LED40.3 (GND), LED41.3 (GND), LED42.3 (GND), LED43.3 (GND), LED44.3 (GND), LED45.3 (GND), LED46.3 (GND), LED47.3 (GND), LED48.3 (GND), LED49.3 (GND), LED50.3 (GND), LED51.3 (GND), LED52.3 (GND), LED53.3 (GND), LED54.3 (GND), LED55.3 (GND), LED56.3 (GND), LED57.3 (GND), LED58.3 (GND), LED59.3 (GND), LED60.3 (GND), LED61.3 (GND), LED62.3 (GND), LED63.3 (GND), LED64.3 (GND), LED65.3 (GND), LED66.3 (GND), LED67.3 (GND), LED68.3 (GND), LED69.3 (GND), LED70.3 (GND), LED71.3 (GND), LED72.3 (GND), LED73.3 (GND), LED74.3 (GND), LED75.3 (GND), LED76.3 (GND), LED77.3 (GND), LED78.3 (GND), LED79.3 (GND), LED80.3 (GND), LED81.3 (GND), LED82.3 (GND); also elsewhere on the board
LED1: LED12.2 (DOUT), LED13.4 (DIN)
LED2: LED24.2 (DOUT), LED25.4 (DIN)
LED3: LED36.2 (DOUT), LED37.4 (DIN)
LED4: LED48.2 (DOUT), LED49.4 (DIN)
LED5: LED60.2 (DOUT), LED61.4 (DIN)
LED6: LED72.2 (DOUT), LED73.4 (DIN)
unnamed: LED1.2 (DOUT), LED2.4 (DIN)
unnamed: LED2.2 (DOUT), LED3.4 (DIN)
unnamed: LED3.2 (DOUT), LED4.4 (DIN)
unnamed: LED4.2 (DOUT), LED5.4 (DIN)
unnamed: LED5.2 (DOUT), LED6.4 (DIN)
unnamed: LED6.2 (DOUT), LED7.4 (DIN)
unnamed: LED7.2 (DOUT), LED8.4 (DIN)
unnamed: LED8.2 (DOUT), LED9.4 (DIN)
unnamed: LED9.2 (DOUT), LED10.4 (DIN)
unnamed: LED10.2 (DOUT), LED11.4 (DIN)
unnamed: LED11.2 (DOUT), LED12.4 (DIN)
unnamed: LED13.2 (DOUT), LED14.4 (DIN)
unnamed: LED14.2 (DOUT), LED15.4 (DIN)
unnamed: LED15.2 (DOUT), LED16.4 (DIN)
unnamed: LED16.2 (DOUT), LED17.4 (DIN)
unnamed: LED17.2 (DOUT), LED18.4 (DIN)
unnamed: LED18.2 (DOUT), LED19.4 (DIN)
unnamed: LED19.2 (DOUT), LED20.4 (DIN)
unnamed: LED20.2 (DOUT), LED21.4 (DIN)
unnamed: LED21.2 (DOUT), LED22.4 (DIN)
unnamed: LED22.2 (DOUT), LED23.4 (DIN)
unnamed: LED23.2 (DOUT), LED24.4 (DIN)
unnamed: LED25.2 (DOUT), LED26.4 (DIN)
unnamed: LED26.2 (DOUT), LED27.4 (DIN)
unnamed: LED27.2 (DOUT), LED28.4 (DIN)
unnamed: LED28.2 (DOUT), LED29.4 (DIN)
unnamed: LED29.2 (DOUT), LED30.4 (DIN)
unnamed: LED30.2 (DOUT), LED31.4 (DIN)
unnamed: LED31.2 (DOUT), LED32.4 (DIN)
unnamed: LED32.2 (DOUT), LED33.4 (DIN)
unnamed: LED33.2 (DOUT), LED34.4 (DIN)
unnamed: LED34.2 (DOUT), LED35.4 (DIN)
unnamed: LED35.2 (DOUT), LED36.4 (DIN)
unnamed: LED37.2 (DOUT), LED38.4 (DIN)
unnamed: LED38.2 (DOUT), LED39.4 (DIN)
unnamed: LED39.2 (DOUT), LED40.4 (DIN)
unnamed: LED40.2 (DOUT), LED41.4 (DIN)
unnamed: LED41.2 (DOUT), LED42.4 (DIN)
unnamed: LED42.2 (DOUT), LED43.4 (DIN)
unnamed: LED43.2 (DOUT), LED44.4 (DIN)
unnamed: LED44.2 (DOUT), LED45.4 (DIN)
unnamed: LED45.2 (DOUT), LED46.4 (DIN)
unnamed: LED46.2 (DOUT), LED47.4 (DIN)
unnamed: LED47.2 (DOUT), LED48.4 (DIN)
unnamed: LED49.2 (DOUT), LED50.4 (DIN)
unnamed: LED50.2 (DOUT), LED51.4 (DIN)
unnamed: LED51.2 (DOUT), LED52.4 (DIN)
unnamed: LED52.2 (DOUT), LED53.4 (DIN)
unnamed: LED53.2 (DOUT), LED54.4 (DIN)
unnamed: LED54.2 (DOUT), LED55.4 (DIN)
unnamed: LED55.2 (DOUT), LED56.4 (DIN)
unnamed: LED56.2 (DOUT), LED57.4 (DIN)
unnamed: LED57.2 (DOUT), LED58.4 (DIN)
unnamed: LED58.2 (DOUT), LED59.4 (DIN)
unnamed: LED59.2 (DOUT), LED60.4 (DIN)
unnamed: LED61.2 (DOUT), LED62.4 (DIN)
unnamed: LED62.2 (DOUT), LED63.4 (DIN)
unnamed: LED63.2 (DOUT), LED64.4 (DIN)
unnamed: LED64.2 (DOUT), LED65.4 (DIN)
unnamed: LED65.2 (DOUT), LED66.4 (DIN)
unnamed: LED66.2 (DOUT), LED67.4 (DIN)
unnamed: LED67.2 (DOUT), LED68.4 (DIN)
unnamed: LED68.2 (DOUT), LED69.4 (DIN)
unnamed: LED69.2 (DOUT), LED70.4 (DIN)
unnamed: LED70.2 (DOUT), LED71.4 (DIN)
unnamed: LED71.2 (DOUT), LED72.4 (DIN)
unnamed: LED73.2 (DOUT), LED74.4 (DIN)
unnamed: LED74.2 (DOUT), LED75.4 (DIN)
unnamed: LED75.2 (DOUT), LED76.4 (DIN)
unnamed: LED76.2 (DOUT), LED77.4 (DIN)
unnamed: LED77.2 (DOUT), LED78.4 (DIN)
unnamed: LED78.2 (DOUT), LED79.4 (DIN)
unnamed: LED79.2 (DOUT), LED80.4 (DIN)
unnamed: LED80.2 (DOUT), LED81.4 (DIN)
unnamed: LED81.2 (DOUT), LED82.4 (DIN)

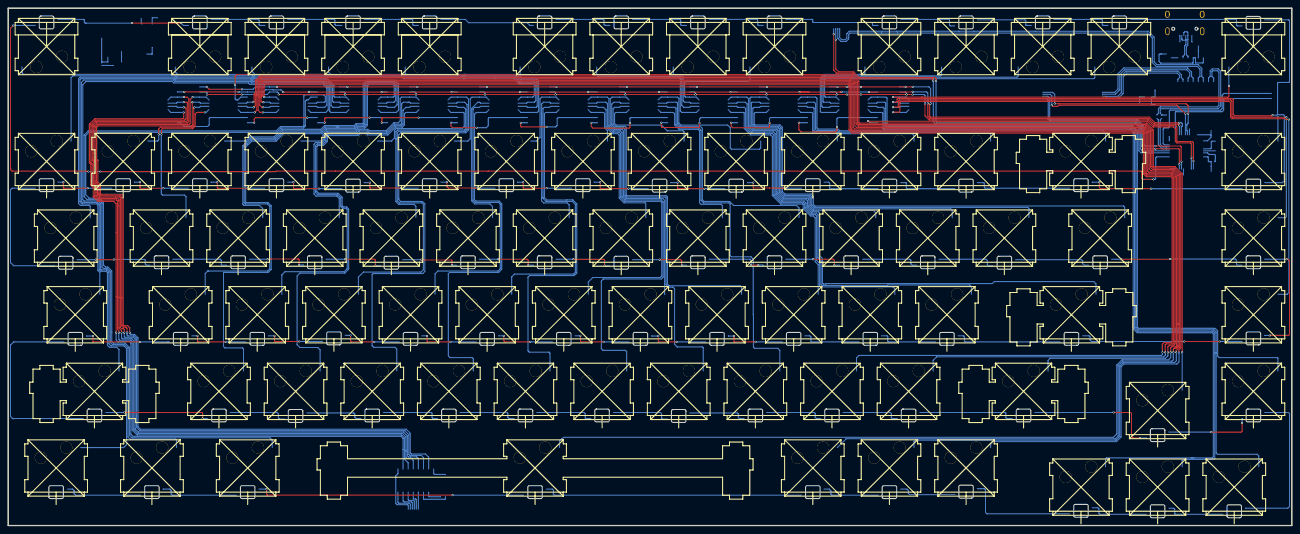
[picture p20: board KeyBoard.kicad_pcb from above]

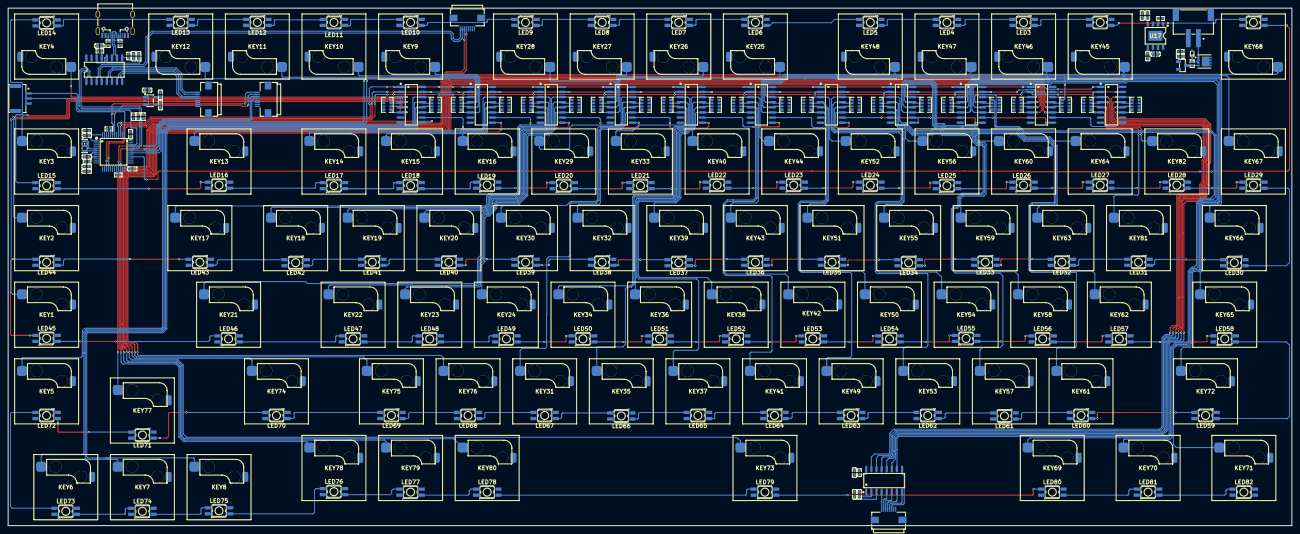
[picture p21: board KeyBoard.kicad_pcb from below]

Board: 2 copper layers, 319.1 x 128.7 mm, 248 parts (248 on the bottom side), 231 nets.

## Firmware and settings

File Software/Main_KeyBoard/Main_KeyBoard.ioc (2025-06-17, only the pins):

Mcu.UserName=STM32F103CBTx
PA10.Signal=USART1_RX
PA11.Signal=USB_DM
PA12.Signal=USB_DP
PA13.Signal=SYS_JTMS-SWDIO
PA14.Signal=SYS_JTCK-SWCLK
PA5.Signal=SPI1_SCK
PA6.Signal=SPI1_MISO
PA9.Signal=USART1_TX
PB10.Signal=I2C2_SCL
PB11.Signal=I2C2_SDA
PB13.Signal=SPI2_SCK
PB15.Signal=SPI2_MOSI
PB3.GPIO_Label=CE
PB3.Signal=GPIO_Output
PB4.GPIO_Label=PL
PB4.Signal=GPIO_Output
PB6.Signal=I2C1_SCL
PB7.Signal=I2C1_SDA
PD0-OSC_IN.Signal=RCC_OSC_IN
PD1-OSC_OUT.Signal=RCC_OSC_OUT

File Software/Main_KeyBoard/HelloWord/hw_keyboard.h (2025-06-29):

#ifndef HELLO_WORD_KEYBOARD_FW_HW_KEYBOARD_H
#define HELLO_WORD_KEYBOARD_FW_HW_KEYBOARD_H

#include "spi.h"


class HWKeyboard
{
public:
    explicit HWKeyboard(SPI_HandleTypeDef* _spi) :
        spiHandle(_spi)
    {
        scanBuffer = &spiBuffer[1];

        // Enable clock
        HAL_GPIO_WritePin(CE_GPIO_Port,CE_Pin,GPIO_PIN_RESET);

        // Init RGB buffer
        for (uint8_t i = 0; i < HWKeyboard::LED_NUMBER; i++)
            SetRgbBufferByID(i, HWKeyboard::Color_t{0, 0, 0});
    }


    static const uint8_t IO_NUMBER = 11 * 8; // Used 11 pcs 74HC165
    static const uint8_t KEY_NUMBER = 82;
    static const uint8_t TOUCHPAD_NUMBER = 6;
    static const uint8_t LED_NUMBER = 85;
    static const uint16_t KEY_REPORT_SIZE = 1 + 16;
    static const uint16_t RAW_REPORT_SIZE = 1 + 32;
    static const uint16_t HID_REPORT_SIZE = KEY_REPORT_SIZE + RAW_REPORT_SIZE;

    enum KeyCode_t : int16_t
    {
        /*------------------------- HID report data -------------------------*/
        LEFT_CTRL = -8,LEFT_SHIFT = -7,LEFT_ALT = -6,LEFT_GUI = -5,
        RIGHT_CTRL = -4,RIGHT_SHIFT = -3,RIGHT_ALT = -2,RIGHT_GUI = -1,

        RESERVED = 0,ERROR_ROLL_OVER,POST_FAIL,ERROR_UNDEFINED,
        A,B,C,D,E,F,G,H,I,J,K,L,M,
        N,O,P,Q,R,S,T,U,V,W,X,Y,Z,
        NUM_1/*1!*/,NUM_2/*2@*/,NUM_3/*3#*/,NUM_4/*4$*/,NUM_5/*5%*/,
        NUM_6/*6^*/,NUM_7/*7&*/,NUM_8/*8**/,NUM_9/*9(*/,NUM_0/*0)*/,
        ENTER,ESC,BACKSPACE,TAB,SPACE,
        MINUS/*-_*/,EQUAL/*=+*/,LEFT_U_BRACE/*[{*/,RIGHT_U_BRACE/*]}*/,
        BACKSLASH/*\|*/,NONE_US/**/,SEMI_COLON/*;:*/,QUOTE/*'"*/,
        GRAVE_ACCENT/*`~*/,COMMA/*,<*/,PERIOD/*.>*/,SLASH/*/?*/,
        CAP_LOCK,F1,F2,F3,F4,F5,F6,F7,F8,F9,F10,F11,F12,
        PRINT,SCROLL_LOCK,PAUSE,INSERT,HOME,PAGE_UP,DELETE,END,PAGE_DOWN,
        RIGHT_ARROW,LEFT_ARROW,DOWN_ARROW,UP_ARROW,PAD_NUM_LOCK,
        PAD_SLASH,PAD_ASTERISK,PAD_MINUS,PAD_PLUS,PAD_ENTER,
        PAD_NUM_1,PAD_NUM_2,PAD_NUM_3,PAD_NUM_4,PAD_NUM_5,
        PAD_NUM_6,PAD_NUM_7,PAD_NUM_8,PAD_NUM_9,PAD_NUM_0,
        PAD_PERIOD , NONUS_BACKSLASH,APPLICATION,POWER,PAD_EQUAL,
        F13,F14,F15,F16,F17,F18,F19,F20,F21,F22,F23,F24, EXECUTE,
        HELP,MENU,SELECT,STOP,AGAIN,UNDO,CUT,COPY,PASTE,FIND,MUTE,VOLUME_UP,VOLUME_DOWN,
        FN = 1000
        /*------------------------- HID report data -------------------------*/
    };

    struct Color_t
    {
        uint8_t r;
        uint8_t g;
        uint8_t b;
    };
    enum SpiWs2812Byte_t : uint8_t
    {
        WS_HIGH = 0xFE,
        WS_LOW = 0xE0
    };

    uint8_t* ScanKeyStates();
    void ApplyDebounceFilter(uint32_t _filterTimeUs = 100);
    uint8_t* Remap(uint8_t _layer = 1);
    void SyncLights();
    bool FnPressed();
    bool KeyPressed(KeyCode_t _key);
    void Press(KeyCode_t _key);
    void Release(KeyCode_t _key);
    uint8_t* GetHidReportBuffer(uint8_t _reportId);
    uint8_t  GetTouchBarState(uint8_t _id = 0);
    void SetRgbBufferByID(uint8_t _keyId, Color_t _color, float _brightness = 1);


    int16_t keyMap[5][IO_NUMBER] = {
        {67,44,45,46,47,24,25,26,27,8,9,10,11,3,
            66,81,63,59,55,51,43,39,32,28,15,14,13,12,2,
            65,80,62,58,54,50,42,38,31,29,19,18,17,16,1,
            64,61,57,53,49,41,37,35,33,23,22,21,20,0,
            71,60,56,52,48,40,36,34,30,75,74,73,76,4,
            70,69,68,72,79,78,77,7,6,5,
            86,84,82,87,85,83}, // TouchBar index

        {ESC,F1,F2,F3,F4,F5,F6,F7,F8,F9,F10,F11,F12,PAD_NUM_LOCK,
            GRAVE_ACCENT,NUM_1,NUM_2,NUM_3,NUM_4,NUM_5,NUM_6,NUM_7,NUM_8,NUM_9,NUM_0,MINUS,EQUAL,BACKSPACE,FN,
            TAB,Q,W,E,R,T,Y,U,I,O,P,LEFT_U_BRACE,RIGHT_U_BRACE,BACKSLASH,DELETE,
            CAP_LOCK,A,S,D,F,G,H,J,K,L,SEMI_COLON,QUOTE,ENTER,INSERT,
            LEFT_SHIFT,Z,X,C,V,B,N,M,COMMA,PERIOD,SLASH,RIGHT_SHIFT,UP_ARROW,HOME,
            LEFT_CTRL,LEFT_GUI,LEFT_ALT,SPACE,RIGHT_ALT,RIGHT_GUI,RIGHT_CTRL,LEFT_ARROW,DOWN_ARROW,RIGHT_ARROW },

        {ESC,F1,F2,F3,F4,F5,F6,F7,F8,F9,F10,F11,F12,PAD_NUM_LOCK,
            GRAVE_ACCENT,NUM_1,NUM_2,NUM_3,NUM_4,NUM_5,NUM_6,NUM_7,NUM_8,NUM_9,NUM_0,MINUS,EQUAL,BACKSPACE,HOME,
            TAB,A,B,C,D,E,F,G,H,I,J,LEFT_U_BRACE,RIGHT_U_BRACE,BACKSLASH,DELETE,
            CAP_LOCK,K,L,M,N,O,P,Q,R,S,SEMI_COLON,QUOTE,ENTER,INSERT,
            LEFT_SHIFT,T,U,V,W,X,Y,Z,COMMA,PERIOD,SLASH,RIGHT_SHIFT,A,PAGE_DOWN,
            LEFT_CTRL,LEFT_GUI,LEFT_ALT,SPACE,RIGHT_ALT,FN,RIGHT_CTRL,LEFT_ARROW,DOWN_ARROW,RIGHT_ARROW }
    };

    volatile bool isRgbTxBusy;
    bool isCapsLocked = false;


private:
    SPI_HandleTypeDef* spiHandle;
    uint8_t spiBuffer[IO_NUMBER / 8 + 1]{};
    uint8_t* scanBuffer;
    uint8_t debounceBuffer[IO_NUMBER / 8 + 1]{};
    uint8_t hidBuffer[HID_REPORT_SIZE]{};
    uint8_t remapBuffer[IO_NUMBER / 8]{};
    uint8_t rgbBuffer[LED_NUMBER][3][8]{};
    uint8_t wsCommit[64] = {0};
    uint8_t brightnessPreDiv = 2; // 1/4
};


#endif

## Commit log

2025-06-17 create PCB && Software
    [Device.kicad_sch, KYE.kicad_sch, KeyBoard.dxf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]
2025-06-18 Completed the schematic drawing, started the PCB process, and updated the firmware to the helloword firmware.
    [KeyBoard.dwg, KeyBoard.kicad_pcb, KeyBoard.kicad_sch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]
2025-06-19 complete layout
    [Device.kicad_sch, KYE.kicad_sch, KeyBoard.kicad_pcb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]
2025-06-20 start generic cabling
    [KeyBoard.kicad_pcb, MCU.kicad_sch]
2025-06-25 Update the PCB layout
    [Device.kicad_sch, KeyBoard.kicad_pcb, KeyBoard.kicad_sch]
2025-06-26 complete Key line
    [KeyBoard.kicad_pcb]
2025-06-26 Complete the non-power line routing
    [Device.kicad_sch, KeyBoard.kicad_pcb]
2025-06-27 change the keyboard
    [Device.kicad_sch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]
2025-06-28 complete desin
    [Device.kicad_sch, Enclosure.dxf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]
2025-06-29 complete all
    [KYE.kicad_sch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]
